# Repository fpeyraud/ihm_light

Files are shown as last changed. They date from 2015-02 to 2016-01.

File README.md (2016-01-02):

# ihm_light
Basic MMI (IHM) for Tryphon racks

## Description :

Composed of 2 buttons and 4 multi-color LEDs, this interface can be used to
- boot a computer,
- trigger the reset button
- trigger an NMI (short PWON button press)
- trigger a forced shutdown (long PWON button press)
- send button down and button up events to the computer via an USB serial connection
- light LEDs individually or all at once according to commands sent via the USB serial connection

## The hardware
The hardware is composed of an Arduino Pro Micro as [sold by Sparkfun](https://www.sparkfun.com/products/12640) or others on Ebay, coupled to a shield which board and schematics is given in the {board} directory. The shield is a double sided PCB which should be easily realised online.

## The code
The goal has been to stay in the arduino paradigm as much as possible whule providing a complete functionnality with as few blocking functions (delay()) as I could. Oh no it's probably not the best code, but it works pretty well.

## How to use the overall project

When the board is powered up, the leds start scrolling until the serial connection is established.
When established, the board acts on the following commands

* `Lwxyz` : Light leds all at once, wxyz represent the color of each led. It can be set according to the following table:
  * 0 : Off
  * R : Red
  * G : Green
  * B : Blue
  * O : Orange
  * P : Purple
  * C : Cyan
  * W : White
  * r : blinking red
  * g : blinking green
  * b : blinking blue
  * o : blinking orange
  * p : blinking purple
  * c : blinking cyan
  * w : blinking white
* `BRn` : Set brightness from 0 (min) to 15 (max)
* `SLnc` : Light one LED number n with color c as desribed above
* `PWOFF` : Trigger a hard Power Off 
* `RESET` : Trigger the reset button
* `NMI` : Trigger a short PWON press

When the buttons are pressed, L or R are sent on the USB serial port, and l or r are sent when buttons are released.

When both L and R buttons are pressed for 3 seconds, the board enters an internal menu with four options. The currently selected option is represented bu the red LED. Option selection is changed by pressing the L button. The currently option is validated by pressing the R button. The functions for each option is :
1. exit menu
2. NMI
3. RESET
4. Power OFF

When no button is pressed for a certain time after entering the menu, it is automatically exited and LED state is restored as before entering the menu.

## And....

and that's all it does so far. Of course we could add a lot more, but for the time being, it just fits my need ;) Feel free to fork and pull request. Thanks for your attendance ;)

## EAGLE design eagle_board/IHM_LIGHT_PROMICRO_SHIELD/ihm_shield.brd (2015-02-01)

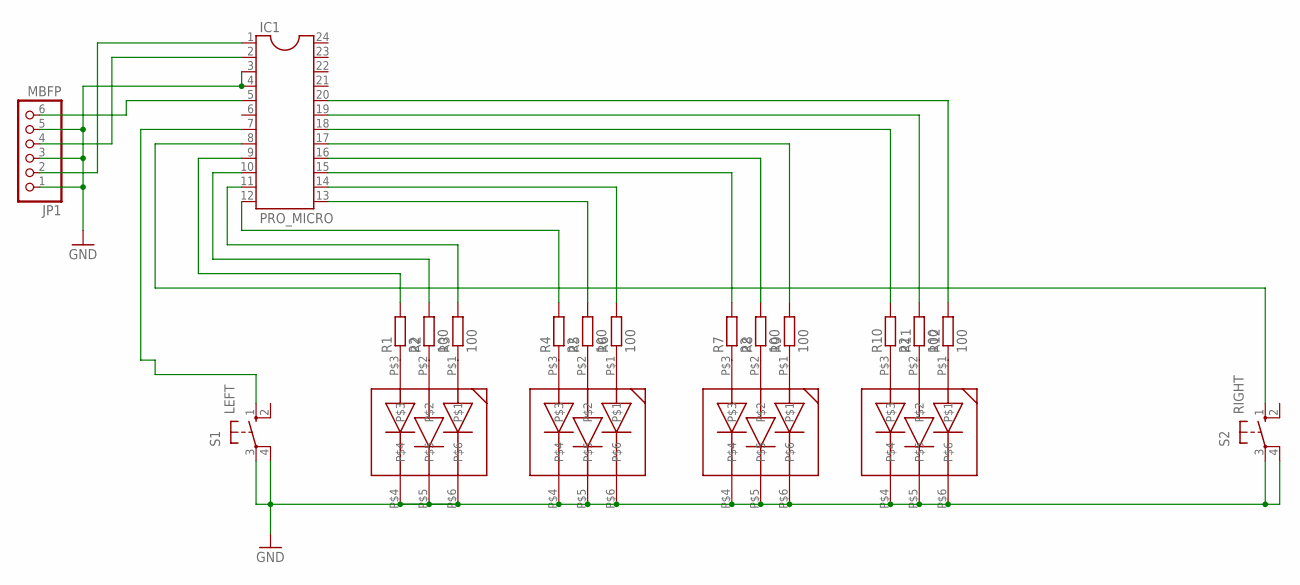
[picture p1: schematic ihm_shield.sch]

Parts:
IC1: PRO_MICRO; DIL24-6
JP1: MBFP; 1X06/90
R1, R4, R7, R10: 22; R0805
R2, R3, R5, R6, R8, R9, R11, R12: 100; R0805
S1: LEFT; B3F-10XX
S2: RIGHT; B3F-10XX
U$1, U$2, U$3, U$4: 5050LED; PLCC-6

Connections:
GND: IC1.3, IC1.4, JP1.1, JP1.3, JP1.5, S1.3, S1.4 (P1), S2.3, S2.4 (P1), U$1.P$4, U$1.P$5, U$1.P$6, U$2.P$4, U$2.P$5, U$2.P$6, U$3.P$4, U$3.P$5, U$3.P$6, U$4.P$4, U$4.P$5, U$4.P$6
unnamed: R4.1, U$2.P$3
unnamed: R5.1, U$2.P$2
unnamed: R6.1, U$2.P$1
unnamed: R7.1, U$3.P$3
unnamed: R8.1, U$3.P$2
unnamed: R9.1, U$3.P$1
unnamed: R1.1, U$1.P$3
unnamed: R2.1, U$1.P$2
unnamed: R3.1, U$1.P$1
unnamed: R10.1, U$4.P$3
unnamed: R11.1, U$4.P$2
unnamed: IC1.1, JP1.2
unnamed: IC1.2, JP1.4
unnamed: IC1.5, JP1.6
unnamed: R12.1, U$4.P$1
unnamed: IC1.20, R12.2
unnamed: IC1.19, R11.2
unnamed: IC1.18, R10.2
unnamed: IC1.17, R9.2
unnamed: IC1.16, R8.2
unnamed: IC1.15, R7.2
unnamed: IC1.14, R6.2
unnamed: IC1.13, R5.2
unnamed: IC1.12, R4.2
unnamed: IC1.11, R3.2
unnamed: IC1.10, R2.2
unnamed: IC1.9, R1.2
unnamed: IC1.7, S1.1 (S)
unnamed: IC1.8, S2.1 (S)

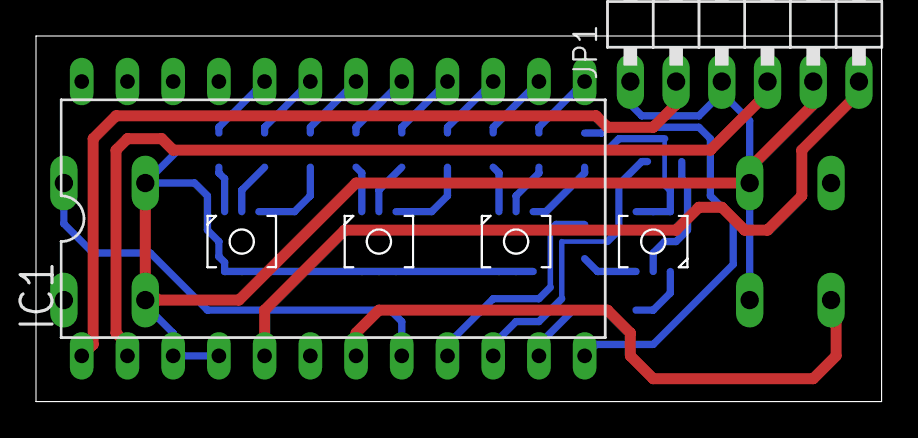
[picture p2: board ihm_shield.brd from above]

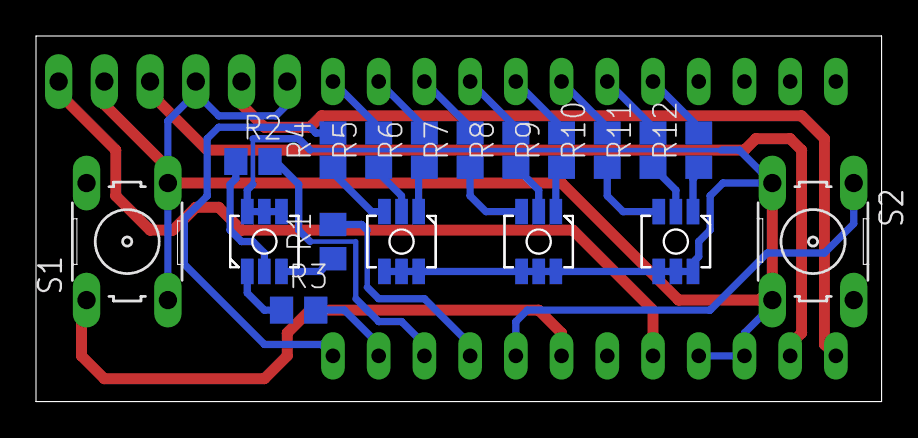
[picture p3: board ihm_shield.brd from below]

Board: 2 copper layers, 47.0 x 20.3 mm, 20 parts (18 on the bottom side), 30 nets.

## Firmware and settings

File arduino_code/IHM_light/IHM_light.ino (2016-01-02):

#include "gendefs.h"

#include "led_scroll.h"



// State machine
// 0 just booted
// 1 initialized, waiting while host boots
// 2 synched
// 3 FrontPanel interface
char state = 0;
char stbkp = 0;

String inputString = "";
boolean fStringComplete = false;
int LbuttonState, RbuttonState;
int LlastButtonState = HIGH;
int RlastButtonState = HIGH;

long LlastDebounceTime = 0;
long RlastDebounceTime = 0;
long debounceDelay = 50;


int pmi_menu = 0;

#include "leds.h"

void setup()
{
  // start serial port at 9600 bps and wait for port to open:
  Serial.begin(9600);
  
  inputString.reserve(6);

  pinMode(PIN_LEFT_BTN,  INPUT_PULLUP);
  pinMode(PIN_RIGHT_BTN, INPUT_PULLUP);

  pinMode(PIN_PWON, INPUT);
  digitalWrite(PIN_PWON, LOW);
  pinMode(PIN_RST,  INPUT);
  digitalWrite(PIN_RST,  LOW);
  pinMode(PIN_PLED, INPUT);
  digitalWrite(PIN_PLED, LOW);
  
  for(int i=0;i<12;i++) pinMode(LedArray[i], OUTPUT);
  for(int i=0;i<4;i++) setLed(i,'W');
  delay(500);
  for(int i=0;i<4;i++) setLed(i,'0');
}

void loop()
{
  process_serial();
  process_commands();
  poll_buttons();
  processLeds(state);
  compute_fsm_transition();
}

void compute_fsm_transition()
{
  static boolean FtempRun=false;
  static long DtempRun=0;

  // Manage interne  
  if(LbuttonState==LOW && RbuttonState==LOW){
    if(!FtempRun){
      // Start temporization
      FtempRun=true;
      DtempRun=millis();
    } else {
      if(millis()-DtempRun > 3000){
        //Temporization expired
        stbkp=state;
        state=3;
        FtempRun=false;
      }
    }
  } else if(FtempRun){
    // reset Temporization flag
    FtempRun=false;
  }

  switch(state){
  case 0:
    //if (get_Power_Led()) state=1;
    state=1;
    delay(500);
    break;
  case 1:
    if (Serial) state=2;
    break;
  case 2:
    break;
  case 3:
    FtempRun=true;
    if(LbuttonState==LOW||RbuttonState==LOW) DtempRun=millis();
    if(millis()-DtempRun > 5000){
      //Temporization expired
      state=stbkp;
      FtempRun=false;
    }
    break;
  }
  // in ANY stat, these conditions apply
  //if (!get_power_led()) state=0; 
}

void poll_buttons()
{
  int reading = digitalRead(PIN_LEFT_BTN);
  if (reading != LlastButtonState) LlastDebounceTime = millis();
  if ((millis() - LlastDebounceTime) > debounceDelay) {
    if (reading != LbuttonState) {
      LbuttonState = reading;
      switch(state){
      case 2:
        if (LbuttonState == LOW) Serial.print("L\n"); else Serial.print("l\n");
        break;
      case 3:
        if (LbuttonState == LOW) pmi_menu=((++pmi_menu)%4);
        break;
      }
    }
  }
  LlastButtonState = reading;
  
  reading = digitalRead(PIN_RIGHT_BTN);
  if (reading != RlastButtonState) RlastDebounceTime = millis();
  if ((millis() - RlastDebounceTime) > debounceDelay) {
    if (reading != RbuttonState) {
      RbuttonState = reading;
      switch(state){
      case 2:
        if (RbuttonState == LOW) Serial.print("R\n"); else Serial.print("r\n");
        break;
      case 3:
        if (RbuttonState == LOW) process_pmi_menu();
        break;
      }
    }
  }
  RlastButtonState = reading;
}

void process_pmi_menu()
{
  switch(pmi_menu){
  case 0:
    break;
  case 1:
    trigger_nmi();
    break;
  case 2:
    trigger_reset();
    break;
  case 3:
    trigger_poweroff();
    break;
  }
  state=2;
  pmi_menu=0;
}

void process_commands()
{
  if(fStringComplete) {
    if(inputString=="PWOFF\n"){
      trigger_poweroff();
    }
    else if(inputString=="RESET\n"){
      trigger_reset();
    }
    else if(inputString=="NMI\n"){
      trigger_nmi();
    }
    else if(inputString.startsWith("SL")){
      int ledidx=inputString.charAt(2)-'0';
      ledidx--;
      //led_state[ledidx] = inputString.charAt(3);
      setLedState(ledidx, inputString.charAt(3));
    }
    else if(inputString.startsWith("BR")){
      setLedBrightness(0,(short)(inputString.substring(2).toInt()));
    }
    else if(inputString.startsWith("L")){
      for(int i=0;i<4;i++){
        //led_state[i]=inputString.charAt(i+1);
        setLedState(i, inputString.charAt(i+1));
      }
      //processLeds();
    } else {
      Serial.print("ERROR\n");
    }
    inputString="";
    fStringComplete=false;
  }
}

void pullPinDown(int pin, const int t) {
  digitalWrite(pin, LOW);
  pinMode(pin, OUTPUT);
  delay(t);
  pinMode(pin, INPUT);
}

void trigger_reset() {
  pullPinDown(PIN_RST, 300);
  state = 0;
}

void trigger_poweroff() {
  pullPinDown(PIN_PWON, 5000);
  state = 0;
}

void trigger_nmi() {
  pullPinDown(PIN_PWON, 300);
}

int process_serial(){
  while(Serial.available()){
    char c = Serial.read();
    inputString += c;
    if (c == '\n') {
      fStringComplete = true;
    }
  }
}

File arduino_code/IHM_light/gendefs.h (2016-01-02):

#define PIN_PWON 1
#define PIN_RST  0
#define PIN_PLED 2

#define PIN_LEFT_BTN  4
#define PIN_RIGHT_BTN 5

#define PIN_LED1R 8
#define PIN_LED1B 9
#define PIN_LED1G 7
#define PIN_LED2R 10
#define PIN_LED2B 16
#define PIN_LED2G 6
#define PIN_LED3R 15
#define PIN_LED3B 18
#define PIN_LED3G 14
#define PIN_LED4R 20
#define PIN_LED4B 21
#define PIN_LED4G 19

// 7 6 16 19

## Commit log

2015-02-01 ready for initial commit
    [ihm_shield.brd, ihm_shield.sch]
2015-12-27 Code rework to handle RGB leds and pin remapping
    [IHM_light.ino]
